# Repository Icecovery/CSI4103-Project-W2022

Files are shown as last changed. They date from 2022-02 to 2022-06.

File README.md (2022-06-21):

# Pen Plotter Project

A CSI4103 Project, University of Ottawa, Winter 2022.

A two-degree-of-freedom robot shaped like a forearm. Any given picture can be drawn on paper using a pen by tracing the result of an edge detection algorithm.

## Showcase

### Image Processing Steps

1. Gray Scale

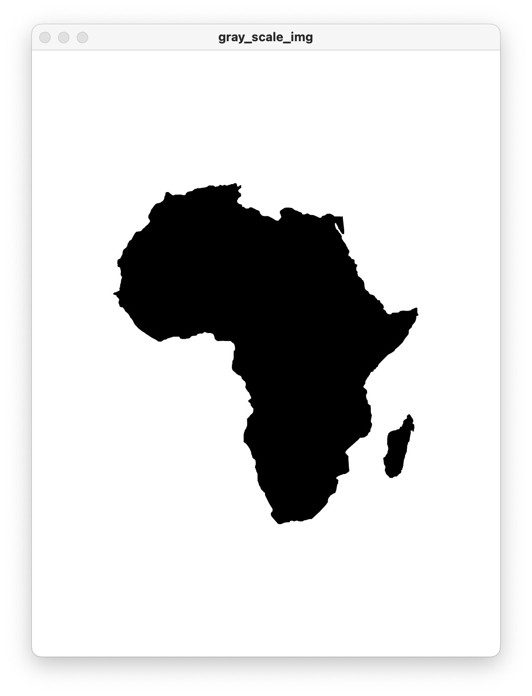
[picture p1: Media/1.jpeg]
Gray Scale


2. Gaussian Blur

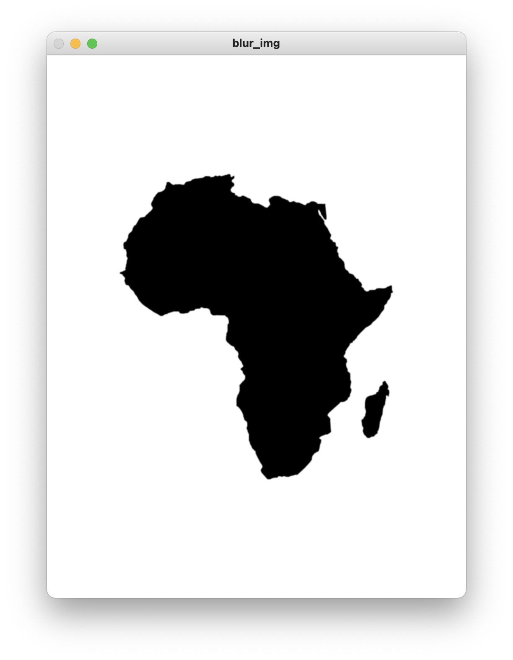
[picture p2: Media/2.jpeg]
Gaussian Blur


3. Canny Edge Detection

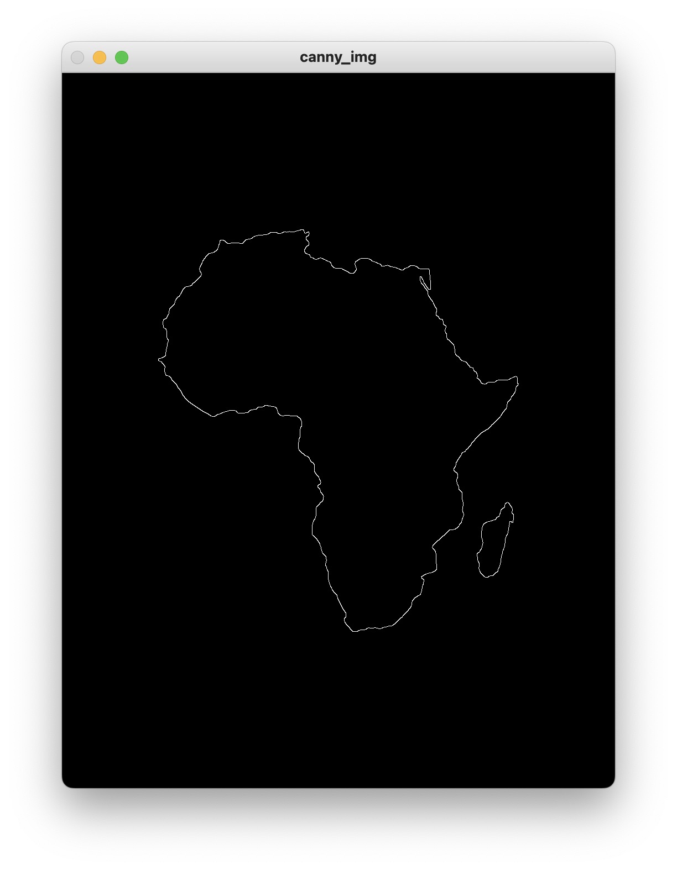
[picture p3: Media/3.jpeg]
Canny Edge Detection


4. Hough Line Transform

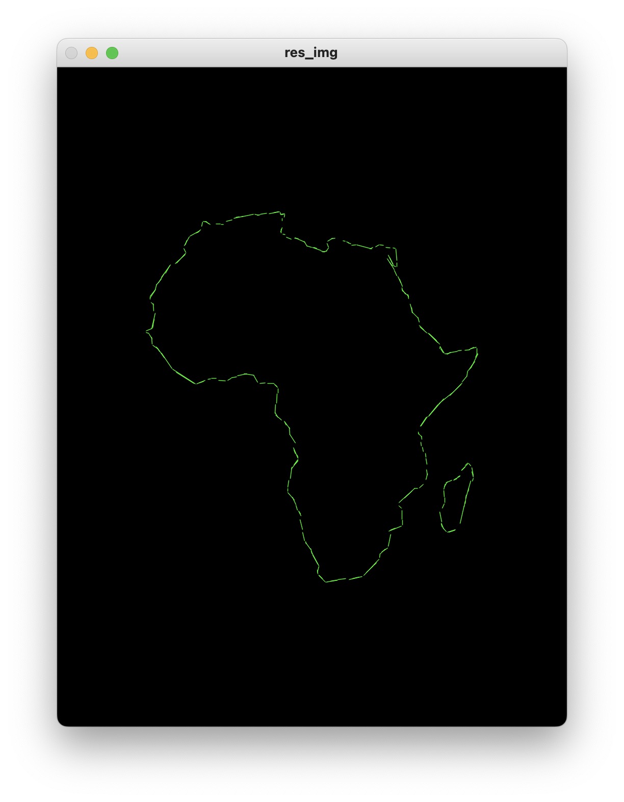
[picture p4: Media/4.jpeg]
Hough Line Transform


5. Spacial Partitioning for Optimization

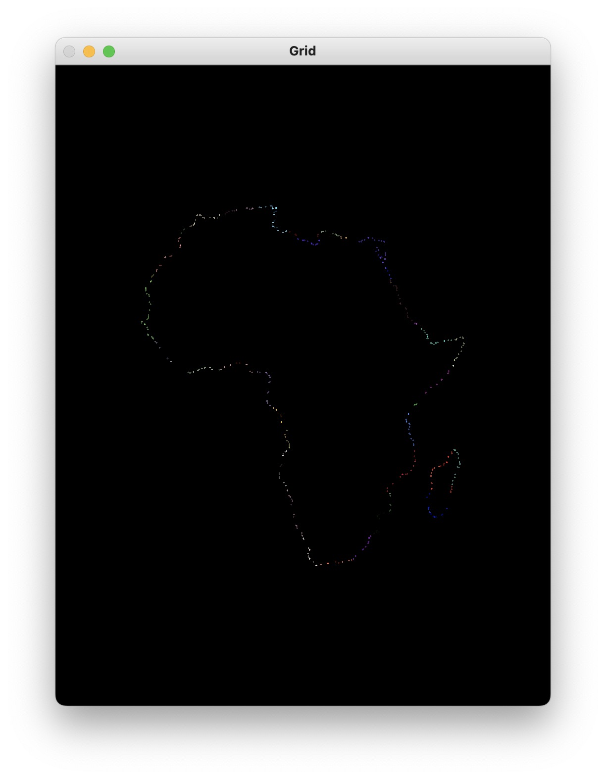
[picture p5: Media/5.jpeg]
Spacial Partitioning for Optimization


6. Optimization Result (Tool Path)

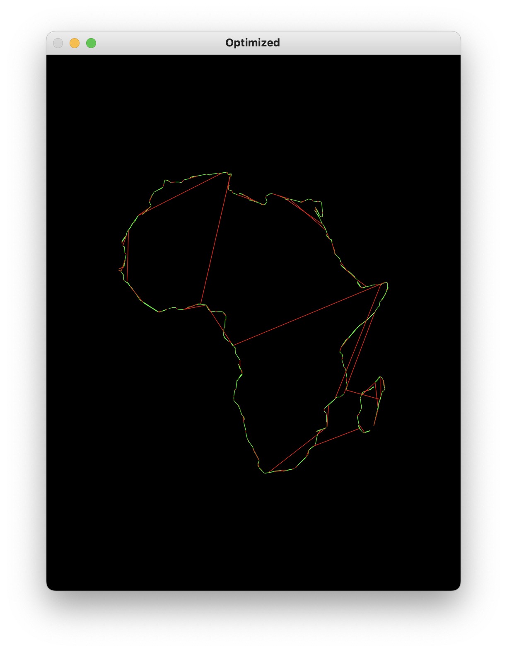
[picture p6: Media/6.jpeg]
Optimization Result (Tool Path)


### Result Sample

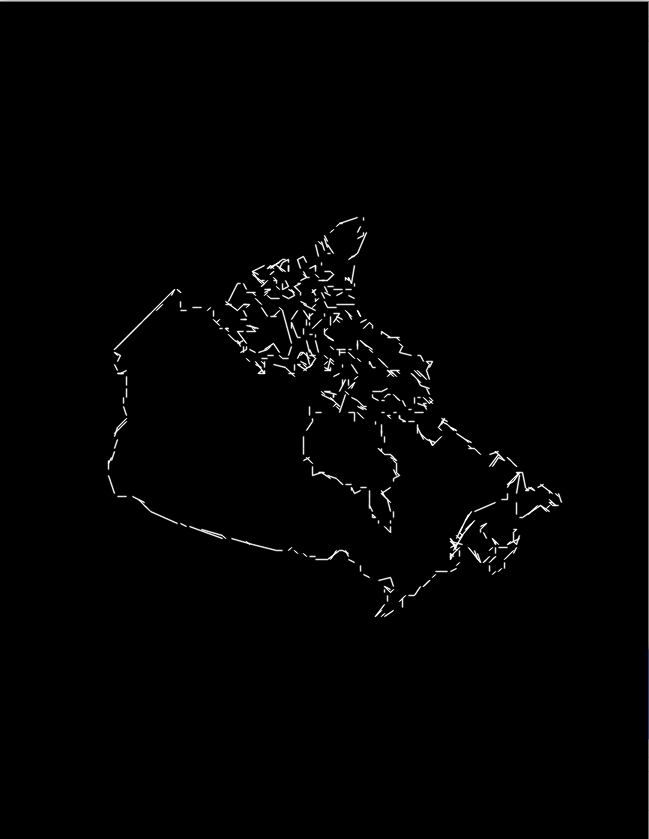
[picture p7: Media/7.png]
From

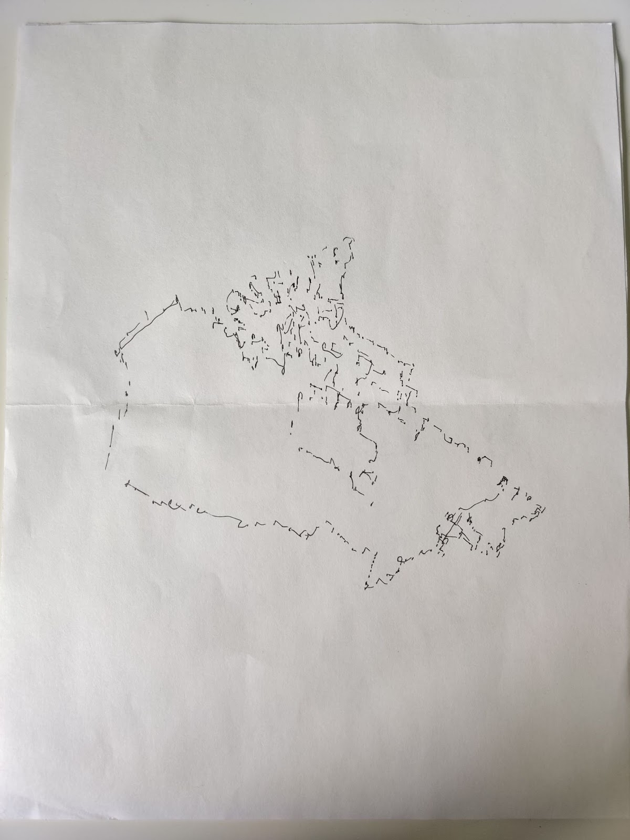
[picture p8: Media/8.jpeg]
Result


### Hardware Setup

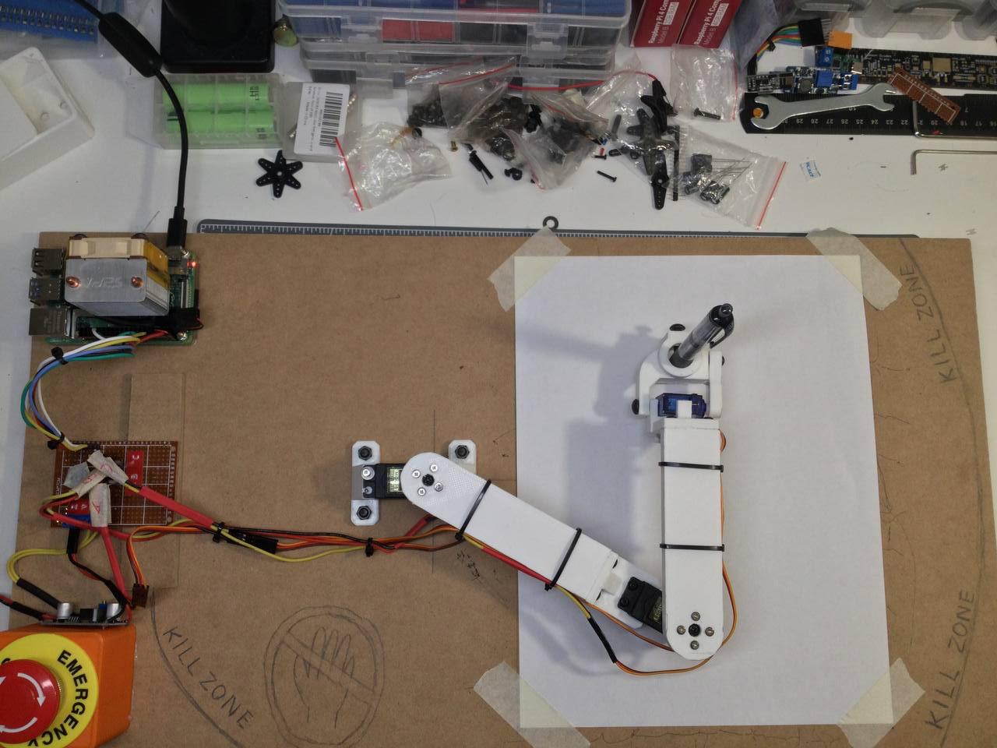
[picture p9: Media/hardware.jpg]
Hardware Setup


## Team Members

- Alexandre Pineau

- Hongyi Lin

- Jingyi Jiang

- Rodger Retanal

- Zitai Peng

## File Hierarchy

### HardwareControl

#### Description

- Code to control the actual hardware servos

#### Language

- Python

#### Package Used

- [gpiozero](https://pypi.org/project/gpiozero/)

- [pigpio](https://pypi.org/project/pigpio/)

#### Installation

- Run `pip install -r requirements.txt`

#### Usage

- Run `python3 HardwareControl`

### ImageProcessing

#### Description

- Image Processing Program that converts input image to list of lines

#### Language

- Python

#### Package Used

- [opencv-python](https://pypi.org/project/opencv-python/)

	- [numpy](https://pypi.org/project/numpy/) (dependency)

#### Installation

- Run `pip install -r requirements.txt`

#### Usage

- Run `python3 ImageProcessing`

### InverseKinematics

#### Description

- Converts output from ImageProcessing to angles instead of points

#### Language

- Python

#### Usage

- Example usage: `python __main__.py -la 5 -lb 5 -s example-input.csv --debug`

### InverseKinematicsDemo

#### Description

- A demo program of the inverse kinematics equations that are going to be used in the project.

- Also useful to find out the length and other parameters of the arm.

#### Language

- Processing (Java)

#### Usage

- Run it using Processing IDE

### Models

#### Description

- The 3D models used to design and print the physical arm

#### File Types

- `f3z`: Autodesk Fusion 360 Archive Files

- `stl`: Standard Triangle Language

#### Usage

- Use Autodesk Fusion 360 to open the `f3z` type files to modify CAD steps

- Use Any 3d model viewer to view `stl` type files, use any 3d printer slicer to slice the model and convert it to G code

## License

MIT License

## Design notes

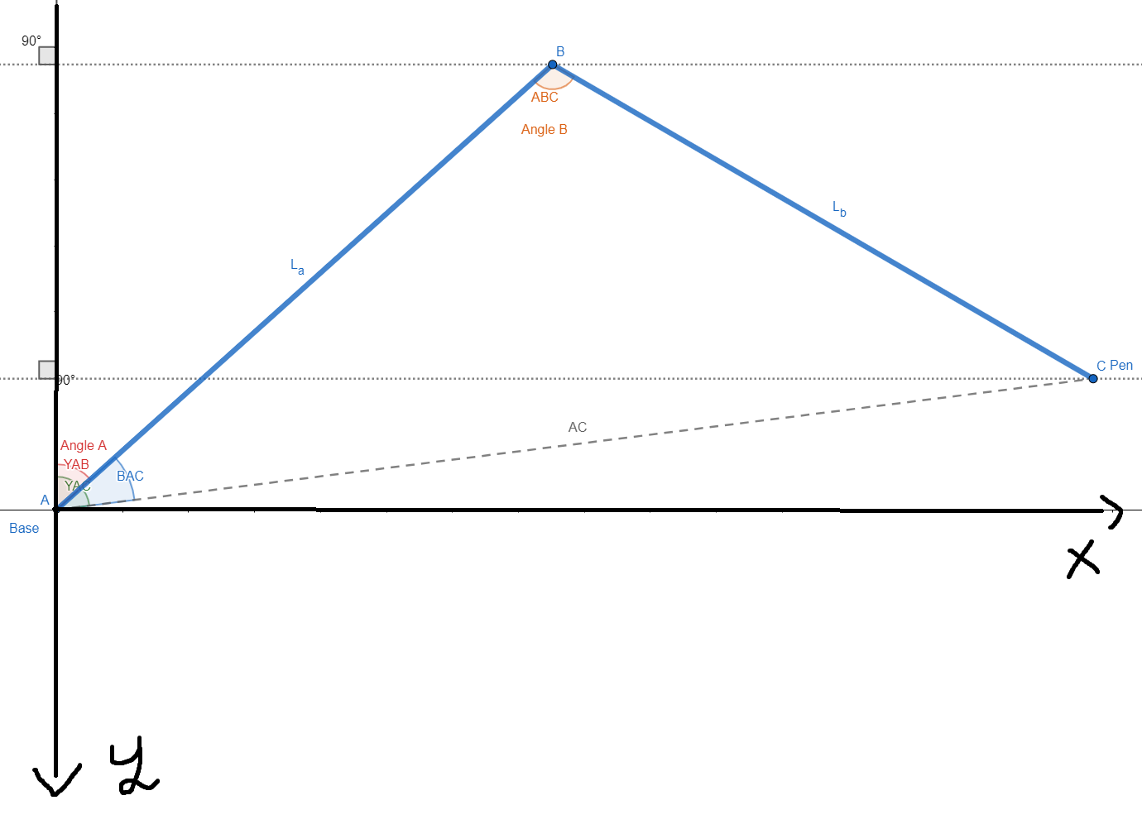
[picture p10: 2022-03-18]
InverseKinematics/angle-format.png

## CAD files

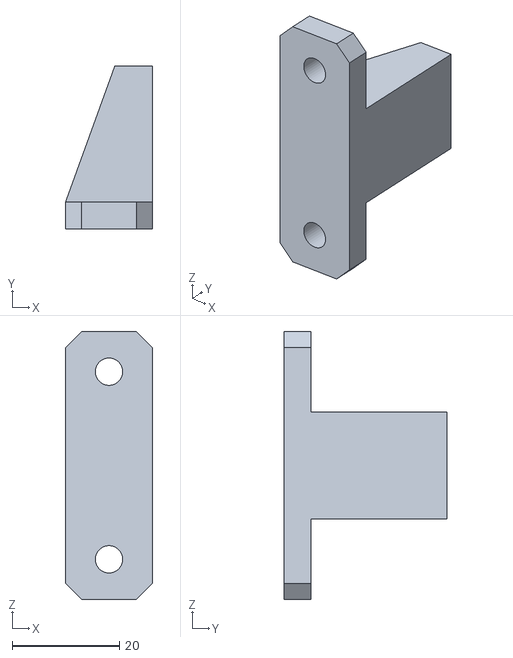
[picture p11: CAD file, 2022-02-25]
Models/ServoAMountBack.stl
16.2 x 30.4 x 50.0

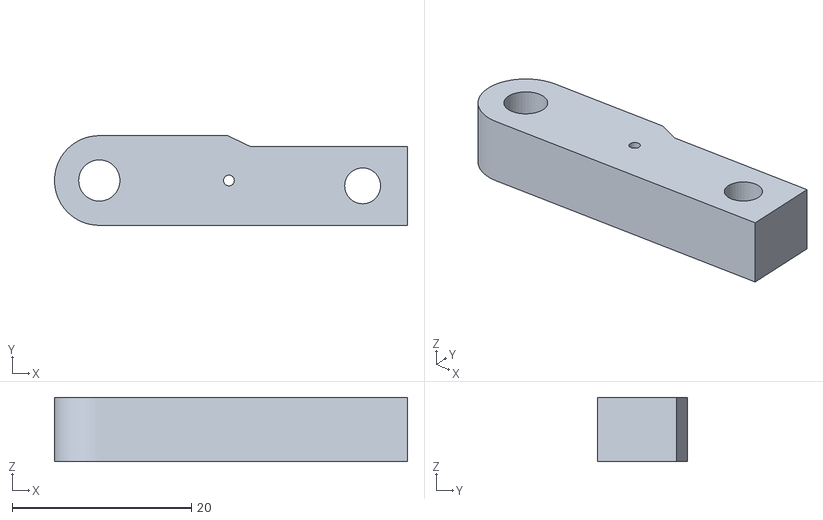
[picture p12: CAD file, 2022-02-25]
Models/ServoArm.stl
39.3 x 10.0 x 7.15

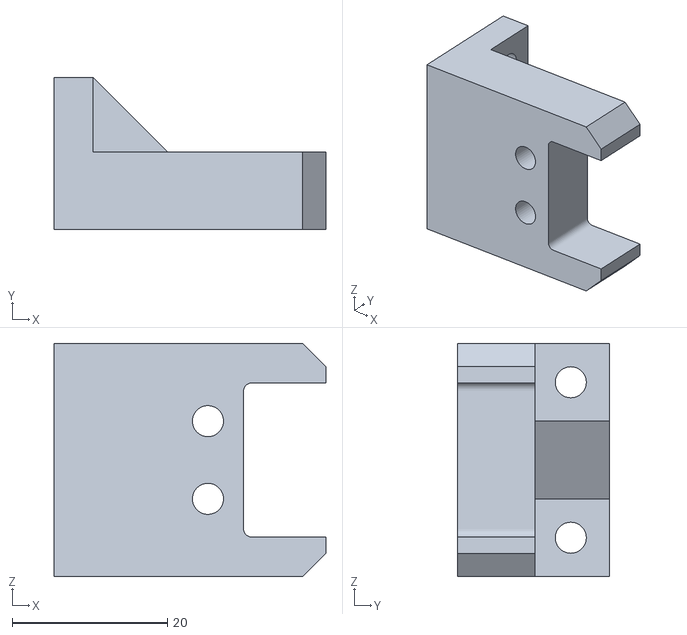
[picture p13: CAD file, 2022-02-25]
Models/ServoBMount.stl
35.0 x 19.6 x 30.0

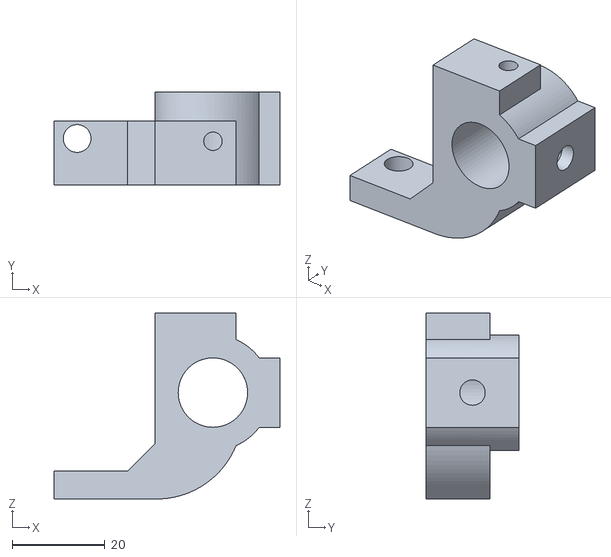
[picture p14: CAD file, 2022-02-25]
Models/PenHolder.stl
48.8 x 20.0 x 40.2

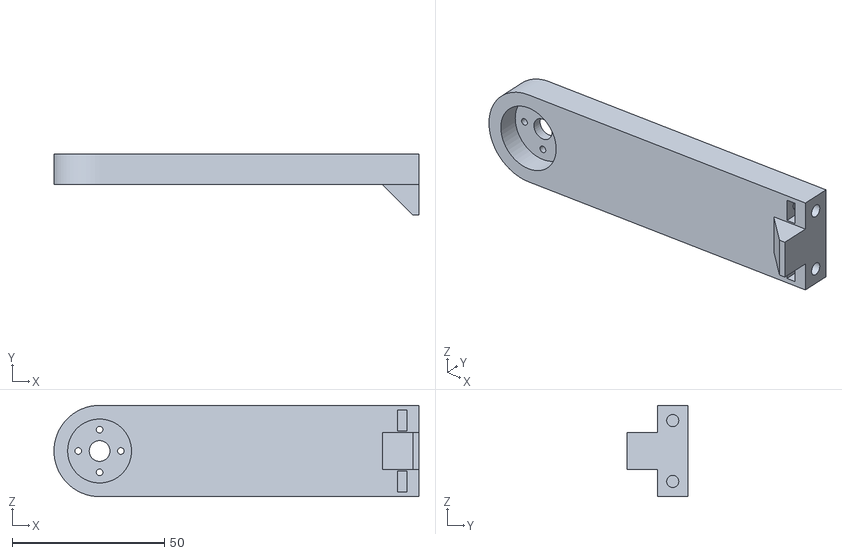
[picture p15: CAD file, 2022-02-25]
Models/Arm.stl
120.0 x 20.0 x 30.0

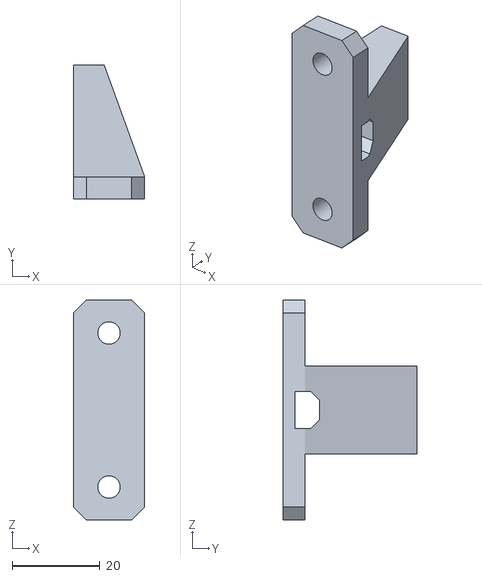
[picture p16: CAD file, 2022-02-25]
Models/ServoAMountFront.stl
16.2 x 30.4 x 50.0

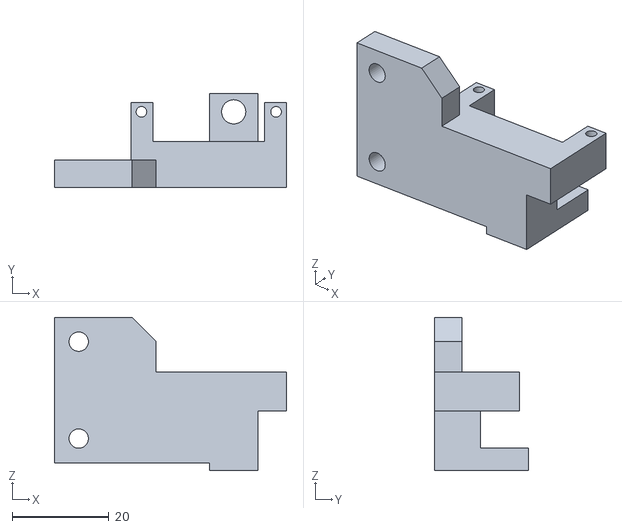
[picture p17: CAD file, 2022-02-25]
Models/ServoCMount.stl
47.9 x 19.5 x 31.6

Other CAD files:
Models/Brachiograph.f3z

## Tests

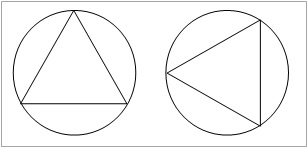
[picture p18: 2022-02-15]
Asset/test_images/Test_image.jpeg

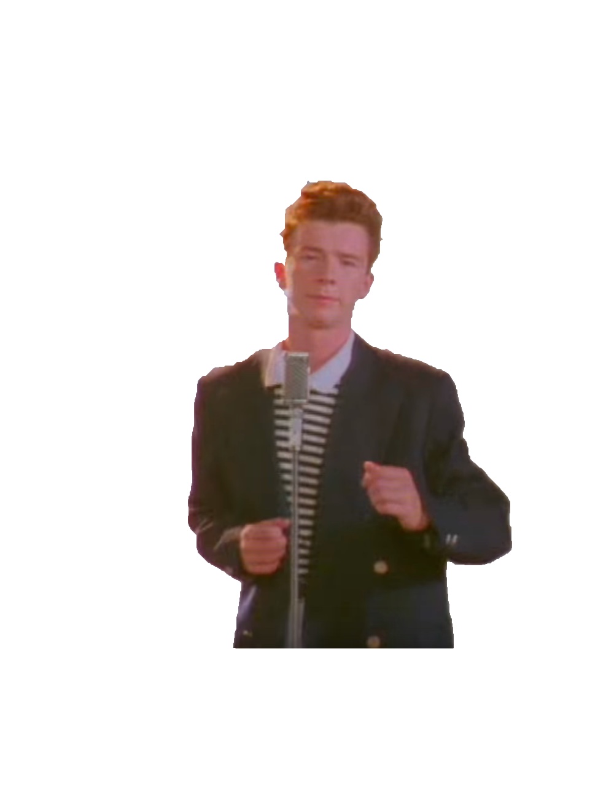
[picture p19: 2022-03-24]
Asset/test_images/Rick.jpg

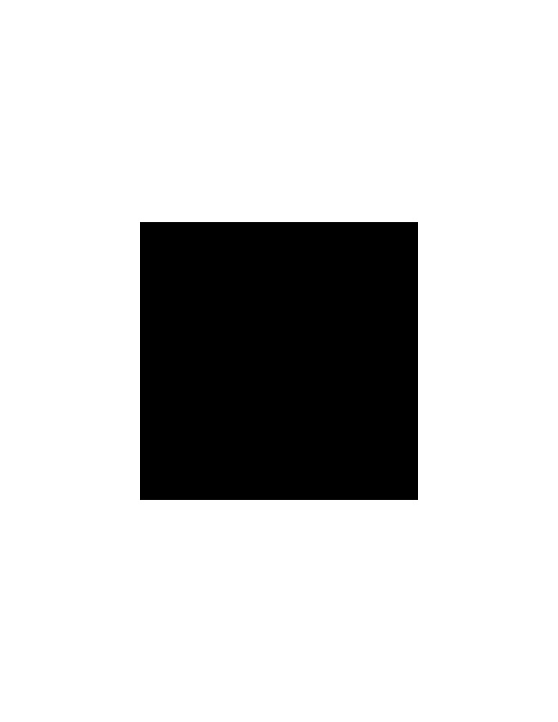
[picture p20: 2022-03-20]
Asset/test_images/Square.jpg

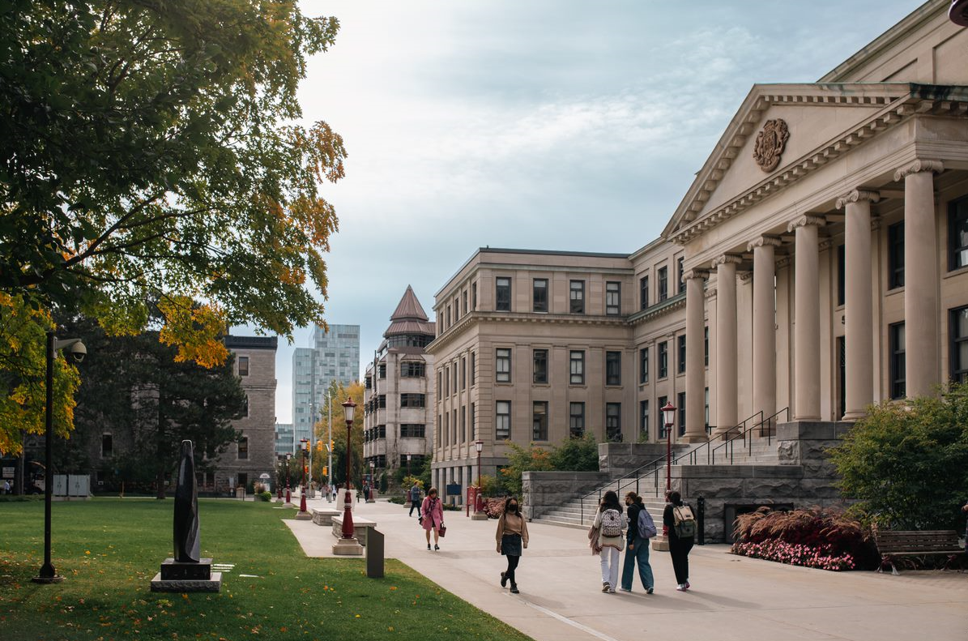
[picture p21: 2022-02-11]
Asset/test_images/uottawa.png

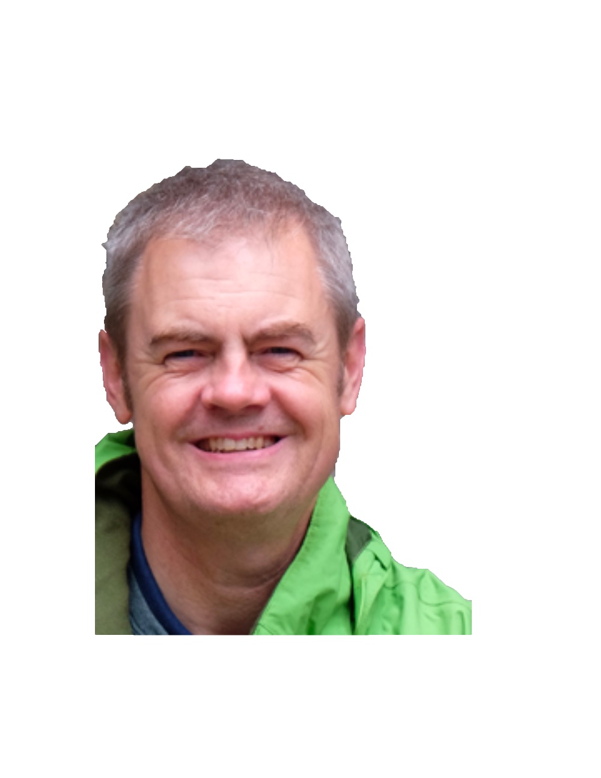
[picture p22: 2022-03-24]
Asset/test_images/Knox.jpg

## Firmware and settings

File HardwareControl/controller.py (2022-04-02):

from time import sleep
from gpiozero import Device, AngularServo, Buzzer
from gpiozero.pins.pigpio import PiGPIOFactory
import progressbar

# PWM pins
# GPIO12 - PWM0 - Servo A
# GPIO13 - PWM1 - Servo B
# GPIO18 - PWM0 - Servo C

SERVO_A_PIN = 12
SERVO_B_PIN = 13
SERVO_C_PIN = 18
BUZZER_PIN = 23

# MG995 (Servo A and B)
# Angle range: 0 - 180 deg
# Pulse width: 500 - 2500 us
# Duty cycle: 2.5 - 12.5%

# SG90 (Servo C)
# Angle range: 0 - 120 deg
# Pulse width: 900 - 2100 us
# Duty cycle: 4.5 - 10.5%

class Controller:
	'''
		This class is used to controll the servos.
	'''

	def __init__(self):
		# https://gpiozero.readthedocs.io/en/stable/api_pins.html#changing-pin-factory
		# use Pi GPIO pin factory to increse accuracy
		Device.pin_factory = PiGPIOFactory()

		# init the buzzer to enable the warning beep
		self.buzzer = Buzzer(BUZZER_PIN)
		self._warning()

		# set up the servos
		self.servo_a = AngularServo(SERVO_A_PIN, 136, 0, 180, 0.5/1000, 2.5/1000)
		self.servo_b = AngularServo(SERVO_B_PIN, 9, 0, 180, 0.5/1000, 2.5/1000)
		self.servo_c = AngularServo(SERVO_C_PIN, 120, 0, 120, 0.9/1000, 2.1/1000)

	def _warning(self):
		self.buzzer.beep(0.1, 0.1, 2, True)
		sleep(1)
		self.buzzer.beep(0.1, 0.1, 2, True)
		sleep(1)
		self.buzzer.beep(1, 3, 1, True)
		sleep(2)

	def _set_servo_a(self, angle):
		# servo A "0 degree": 0 deg
		self.servo_a.angle = angle

	def _set_servo_b(self, angle):
		# servo B dead zone: 163
		# servo B "0 degree": 9 deg
		# reversed
		self.servo_b.angle = min(163, 180 - angle - 9)

	def _set_servo_c(self, isDown):
		self.servo_c.angle = 100 if isDown else 120

		# disable after movement to stop it from making noise
		sleep(0.1)
		self.servo_c.angle = None
	
	def _reset_servos(self):
		self._set_servo_a(0)
		self._set_servo_b(0)
		self._set_servo_c(False)

	def clean_up(self):
		self.servo_a.angle = None
		self.servo_b.angle = None
		self.servo_c.angle = None

	def draw(self, instructions):
		'''
			Use angles to control the servos to move the arms and pen to draw.
		'''

		print("Drawing...")

		for instruction in progressbar.progressbar(instructions):
			if (type(instruction) is bool): # servo C command
				self._set_servo_c(instruction)
			elif (type(instruction) is tuple): # servo A and B command
				self._set_servo_a(instruction[0])
				self._set_servo_b(instruction[1])
			elif (type(instruction) is float): # delay command
				sleep(instruction)
			else:
				raise NotImplementedError
		
		sleep(1)
		
		self._reset_servos()
		sleep(1)

		print("Complete")

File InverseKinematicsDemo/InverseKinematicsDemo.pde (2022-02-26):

float sizeMult = 1.5; // size multiplier to make stuff easier to see

PVector pageSize = new PVector(216, 279);
PVector originPoint = new PVector(200, 100); // origin point of the paper

PVector jointA = PVector.add(originPoint, new PVector(-50, pageSize.y/2)); // origin point of the arm
PVector jointB = new PVector(100, 100);
PVector target = new PVector(200, 200);
float La = 160; // length of arm a
float Lb = 150; // length of arm b

float angleA; // angle of the frist joint
float angleB; // angle of the second joint

float smallestA = Float.POSITIVE_INFINITY;
float smallestB = Float.POSITIVE_INFINITY;

ArrayList<PVector> points = new ArrayList<PVector>();

void setup()
{
  size(800, 800);
}

void draw()
{
  background(0);
  scale(sizeMult);
  
  // handle mouse press event
  if (mousePressed)
  {
    if (mouseButton == LEFT) // draw
    {
      // make sure it is in range
      if (mouseX / sizeMult > originPoint.x && mouseX / sizeMult < originPoint.x + pageSize.x && mouseY / sizeMult > originPoint.y &&  mouseY / sizeMult < originPoint.y + pageSize.y)
      {
          points.add(new PVector(mouseX / sizeMult, mouseY / sizeMult));
      }
    }
    else if (mouseButton == RIGHT) // clear
    {
      points = new ArrayList<PVector>();
    }
  }
  
  // get target position
  target = new PVector(clamp(mouseX / sizeMult, originPoint.x, originPoint.x + pageSize.x), 
                       clamp(mouseY / sizeMult, originPoint.y, originPoint.y + pageSize.y));
  
  float AC = PVector.dist(jointA, target);
  float BAC = acos((sq(La) + sq(AC) - sq(Lb))/(2.0 * La * AC));
  float YAC = asin((target.x - jointA.x) / AC);
  float YAB = (target.y < jointA.y) ? (PI - YAC - BAC) : (YAC - BAC);
  
  // position is reletive to A
  float Bx = sin(YAB) * La;
  float By = sin(HALF_PI - YAB) * La;
  
  jointB = new PVector(Bx, By).add(jointA);
  
  // drawing
  drawPage();
  drawPath();
  drawArm();
  
  angleA = degrees(YAB);
  angleB = degrees(acos((sq(La) + sq(Lb) - sq(AC))/(2.0 * La * Lb)));
  
  smallestA = min(angleA, smallestA);
  smallestB = min(angleB, smallestB);
  
  println("A " + angleA + " B " + angleB + " A min " + smallestA + " B min " + smallestB);
}

void drawPage()
{
  noStroke();
  rect(originPoint.x, originPoint.y, pageSize.x, pageSize.y);
}

void drawPath()
{
  strokeWeight(2);
  stroke(0, 0, 0);
  for (int i = 0; i < points.size(); i++)
  {
    PVector p = points.get(i);
    point(p.x, p.y);
  }
}

void drawArm()
{
  strokeWeight(5);
  
  stroke(100, 100, 100);
  line(jointA.x, jointA.y, jointB.x, jointB.y);
  line(target.x, target.y, jointB.x, jointB.y);
  
  strokeWeight(10);
  
  stroke(255, 0, 0);
  point(jointA.x, jointA.y);
  
  stroke(0, 255, 255);
  point(jointB.x, jointB.y);
  
  stroke(0, 255, 0);
  point(target.x, target.y);
  
}

float clamp(float v, float min, float max)
{
  return min(max(v, min), max);
}

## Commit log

2022-02-20 Added Inverse Kinematics Demo project
2022-02-20 Added preliminary inverse kinematics script
    [example.csv]
2022-02-20 Cleaned up outputs and updated README
    [example-input.csv, example-output.csv]
2022-02-25 Added 3D models for the arm
    [Arm.stl, Brachiograph.f3z, PenHolder.stl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]
2022-02-25 Changed parameters in inverse kinematics demo to match physical design
2022-02-26 Added parameters and updated pipeline.sh
    [example-input.csv, example-output.csv]
2022-03-04 Archive inverse kinematics stuff
2022-03-05 Fixed incorrect angle calculation on servo b
    [controller.py]
2022-03-05 Fixed issue with flipped y axis
2022-03-05 Release servos when keyboard interrupt
2022-03-12 Added 4 test cases to inverse kinematics
2022-03-20 Fixed missing line issue in path optimizer
    [controller.py]
